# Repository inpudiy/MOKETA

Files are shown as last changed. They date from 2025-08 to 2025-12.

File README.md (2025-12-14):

# MOKETA

MOKETA is an open-source unibody 42-key wireless keyboard with MX switches, per-key LEDs, status indicators, a 3D-printed box-mount case, and a hot-swappable Pro Micro–compatible controller.

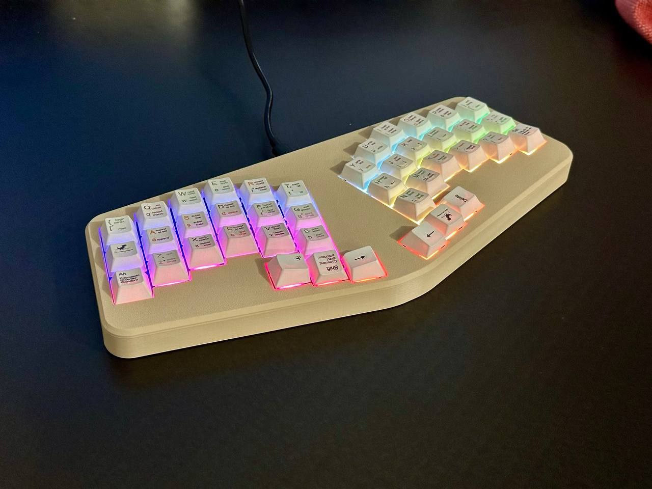
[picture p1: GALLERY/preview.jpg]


[Build Guide](BUILD.md) | [ZMK Firmware](https://github.com/inpudiy/zmk-MOKETA)

## Features

- Unibody form factor with a 15 degree angle between halves
- 42-key column-staggered layout with MX switches
- 3D-printed box mount case
- 4 status LEDs inspired by the Aroum project
- Per-switch SK6812MINI-E LEDs
- Pro Micro compatible microcontroller with hot-swap (nice!nano, SuperMini NRF52840, Mikoto, or another)
- Optimized for wireless use: hardware power switch, reset button, battery solder pads, and ZMK firmware

## PCB Image




## Bill of materials

| Component | Qty/Pin |
| --- | --- |
| Pro Micro board: Super Mini nRF52840 / nice!nano | 1 |
| MSK12C02 Slide Switch | 1 |
| TS342A2P | 1 |
| 50mm Industrial H62 brass wire 0.5mm thickness | 1 |
| 0805 Led | 4 |
| 0805 Resitor | 4 |
| Silicone bumpers | 6 |
| Machine Pin Header Female | 24 |
| PG1511 hot-swap socket | 42 |
| Diode 1N4148W (SOD-123) | 42 |
| MX switches | 42 |
| SK6812MINI-E | 42 |
| Silicone (Optional)

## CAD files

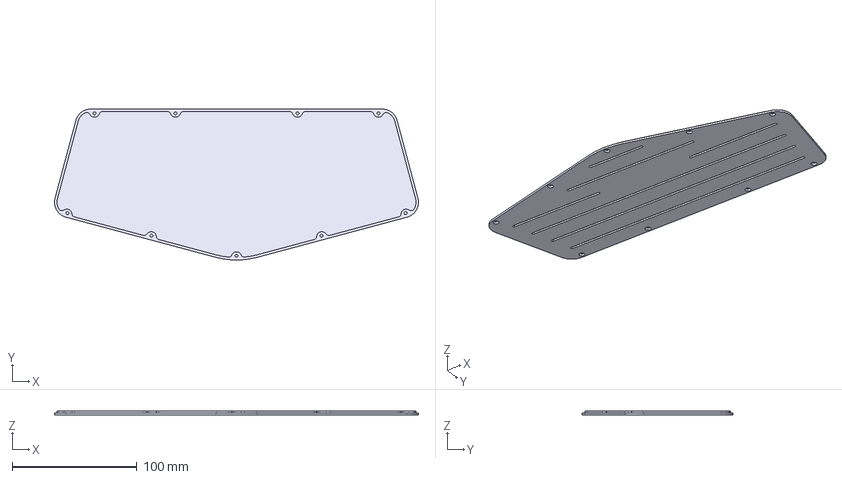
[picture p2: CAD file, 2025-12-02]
CASE/turtle/MOKETA-bottom.step
291.8 x 121.0 x 3.00 mm

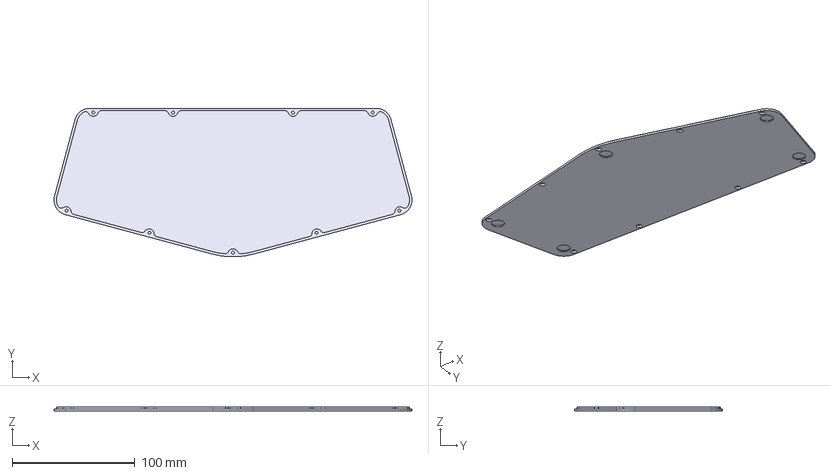
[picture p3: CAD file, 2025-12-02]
CASE/turtle/MOKETA-bottom-for-siliconepads-10mm.step
291.8 x 121.0 x 3.00 mm

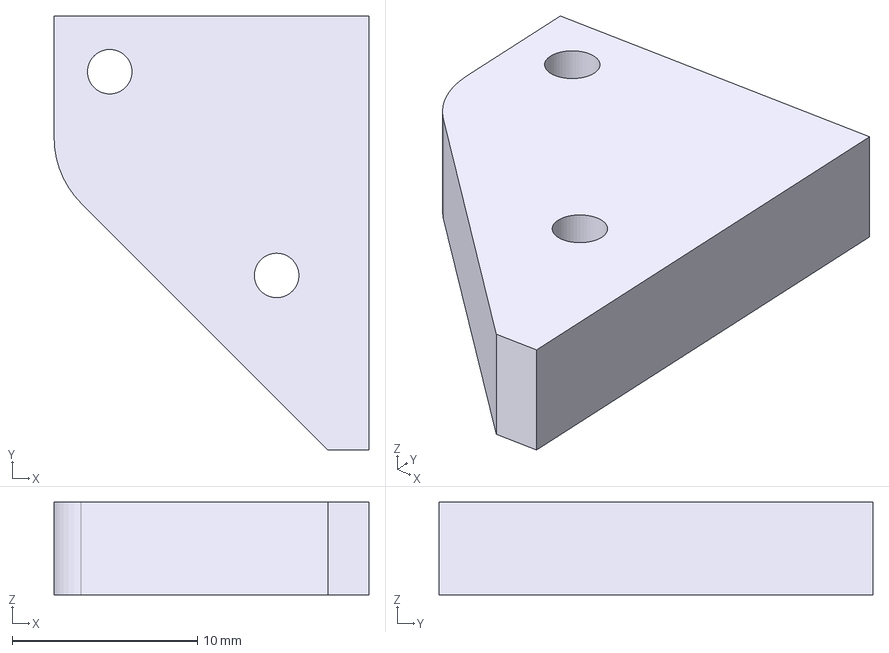
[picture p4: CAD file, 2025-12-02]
CASE/turtle/MOKETA-top-filler-mcu-around-left.step
17.0 x 23.4 x 5.00 mm

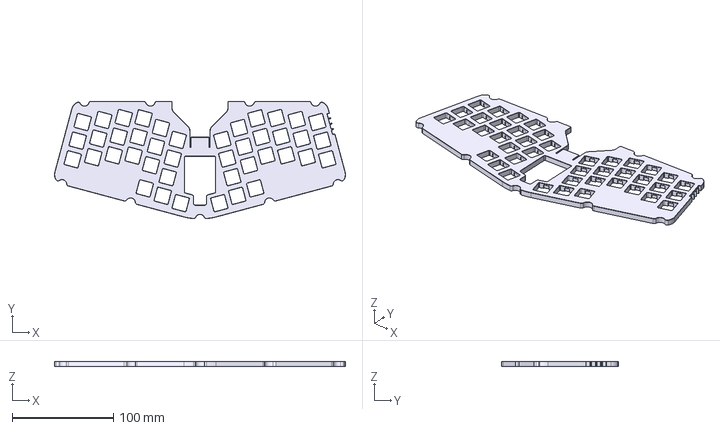
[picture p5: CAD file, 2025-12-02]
CASE/turtle/MOKETA-switchplate.step
286.8 x 115.6 x 5.00 mm

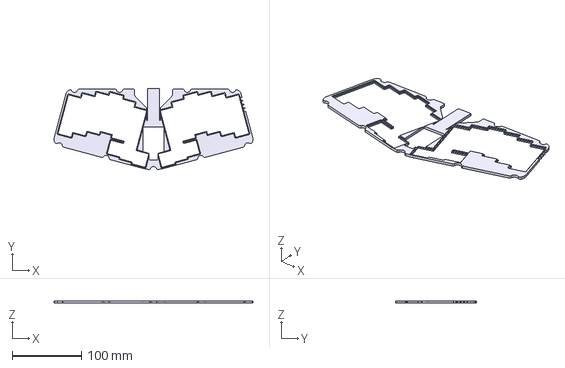
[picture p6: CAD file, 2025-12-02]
CASE/turtle/MOKETA-top-filler.step
286.8 x 116.4 x 3.00 mm

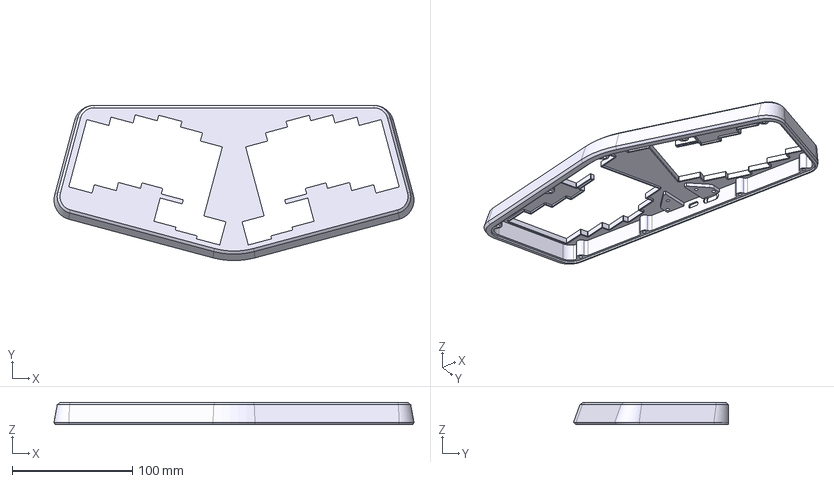
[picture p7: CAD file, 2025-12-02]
CASE/turtle/MOKETA-top.step
300.0 x 129.2 x 18.6 mm

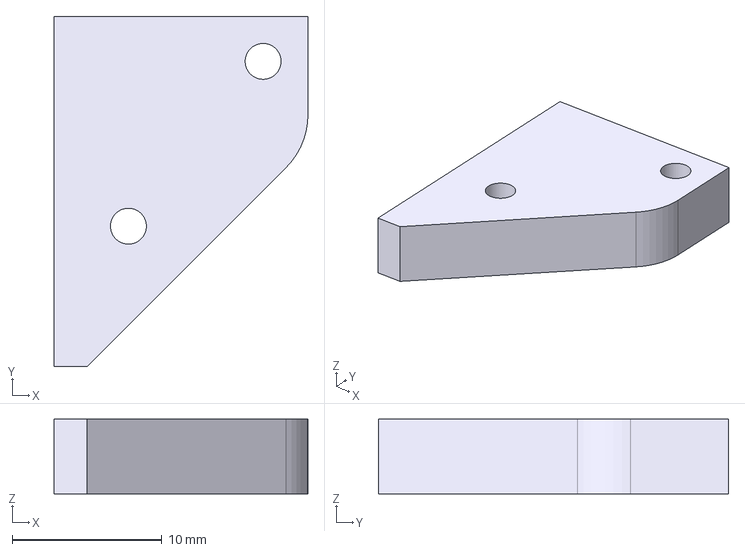
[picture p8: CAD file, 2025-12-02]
CASE/turtle/MOKETA-top-filler-mcu-around-right.step
17.0 x 23.4 x 5.00 mm

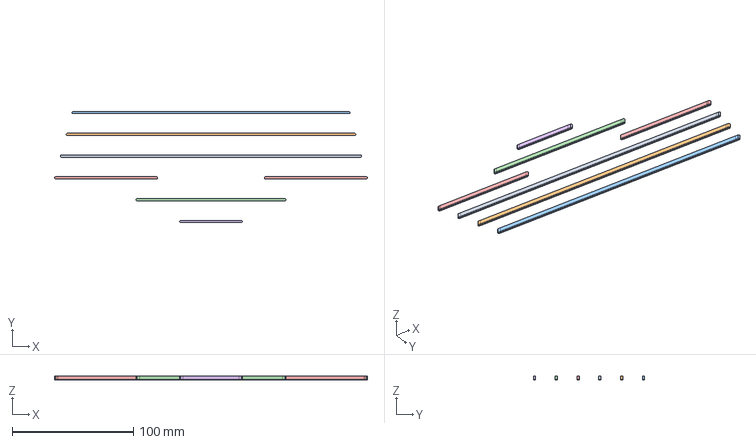
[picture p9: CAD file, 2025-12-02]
CASE/turtle/MOKETA-anti-slippery-legs.step
258.5 x 92.0 x 3.40 mm

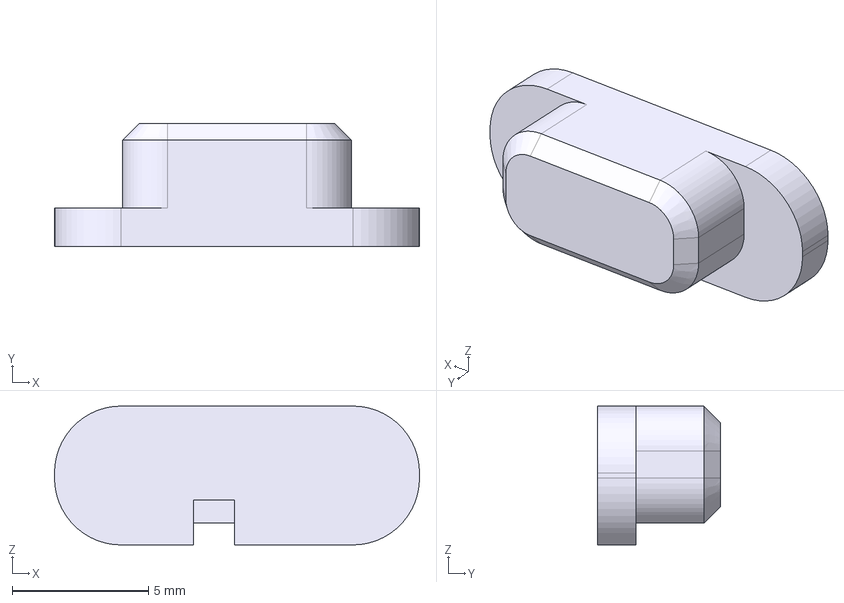
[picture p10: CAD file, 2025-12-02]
CASE/turtle/MOKETA-powerswitch-pusher.step
13.4 x 4.50 x 5.10 mm

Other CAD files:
CASE/turtle/MOKETA-bottom-for-siliconepads-8mm.step
CASE/turtle/MOKETA-top-with-moketa.step
CASE/turtle/MOKETA-bottom-filler.step

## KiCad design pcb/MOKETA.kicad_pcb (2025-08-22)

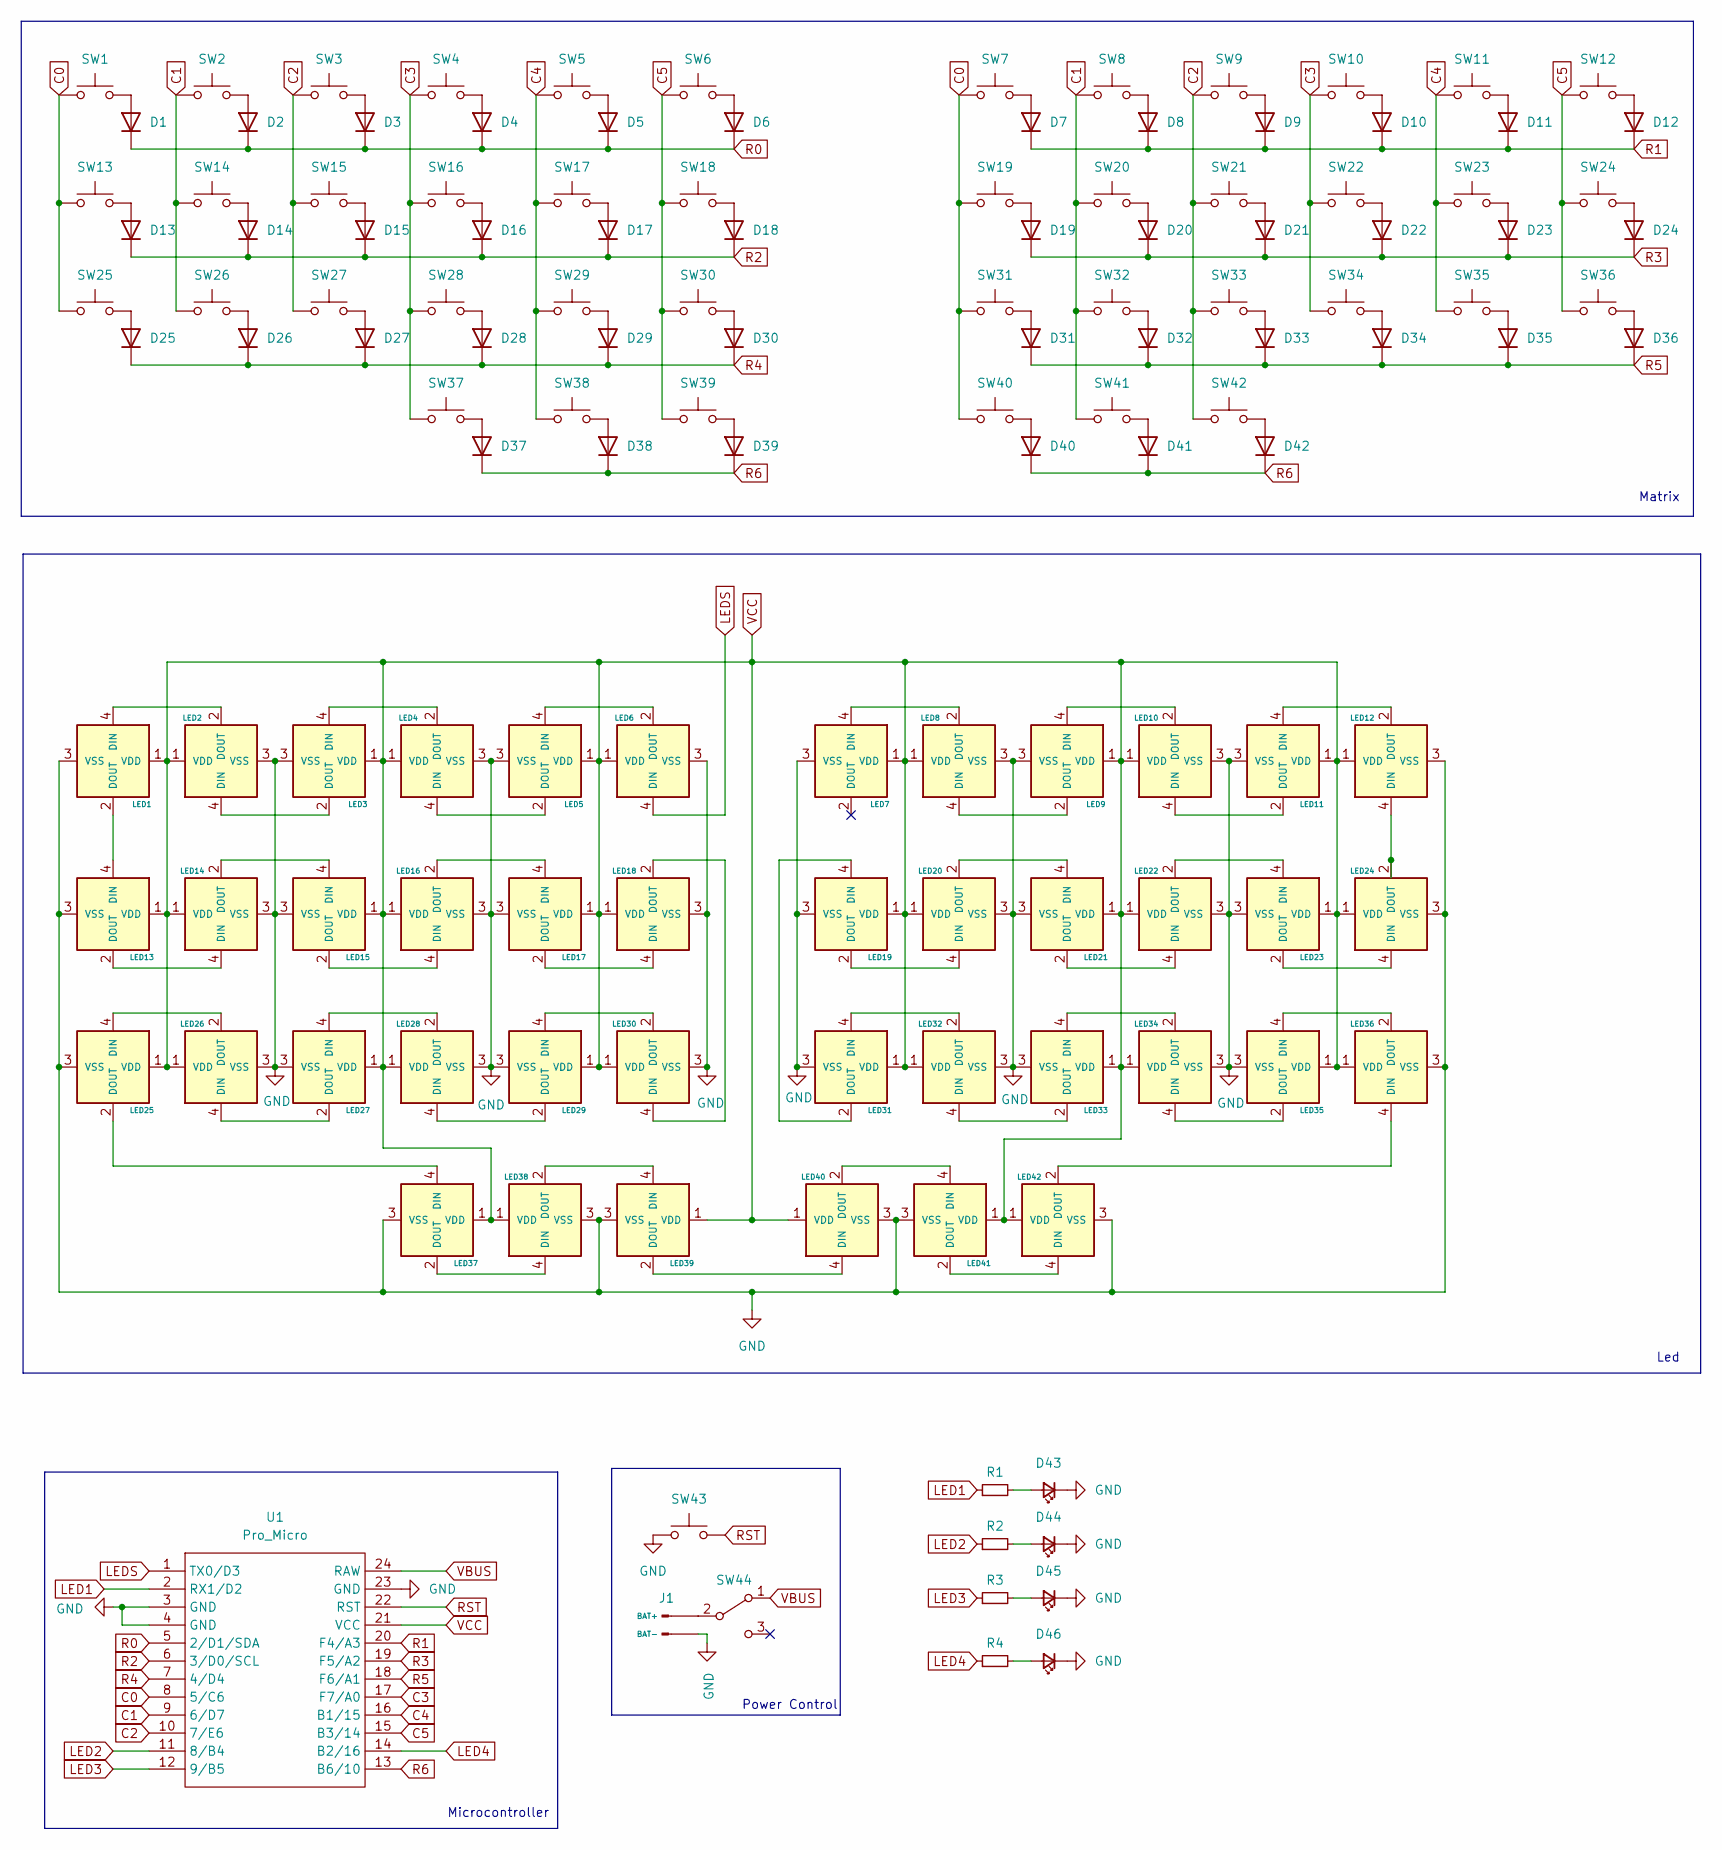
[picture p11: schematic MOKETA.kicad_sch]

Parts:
D1, D2, D3, D4, D5, D6, D7, D8, D9, D10, D11, D12, D13, D14, D15, D16, D17, D18, D19, D20, D21, D22, D23, D24, D25, D26, D27, D28, D29, D30, D31, D32, D33, D34, D35, D36, D37, D38, D39, D40, D41, D42: Diode; D_SOD-123
D43, D44, D45, D46: LED_1206
J1: J_BATTERY
LED1, LED2, LED3, LED4, LED5, LED6, LED7, LED8, LED9, LED10, LED11, LED12, LED13, LED14, LED15, LED16, LED17, LED18, LED19, LED20, LED21, LED22, LED23, LED24, LED25, LED26, LED27, LED28, LED29, LED30, LED31, LED32, LED33, LED34, LED35, LED36, LED37, LED38, LED39, LED40, LED41, LED42: YS-SK6812MINI-E
R1, R2, R3, R4: R_1206_3216
SW1, SW2, SW3, SW4, SW5, SW6, SW7, SW8, SW9, SW10, SW11, SW12, SW13, SW14, SW15, SW16, SW17, SW18, SW19, SW20, SW21, SW22, SW23, SW24, SW25, SW26, SW27, SW28, SW29, SW30, SW31, SW32, SW33, SW34, SW35, SW36, SW37, SW38, SW39, SW40, SW41, SW42: SW_PUSH
SW43: Reset; SW_TACT
SW44: MSK-12C02
U1: Pro_Micro; U_PRO_MICRO

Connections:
C0: SW1.1, SW7.1, SW13.1, SW19.1, SW25.1, SW31.1, SW40.1, U1.8 (5/C6)
C1: SW2.1, SW8.1, SW14.1, SW20.1, SW26.1, SW32.1, SW41.1, U1.9 (6/D7)
C2: SW3.1, SW9.1, SW15.1, SW21.1, SW27.1, SW33.1, SW42.1, U1.10 (7/E6)
C3: SW4.1, SW10.1, SW16.1, SW22.1, SW28.1, SW34.1, SW37.1, U1.17 (F7/A0)
C4: SW5.1, SW11.1, SW17.1, SW23.1, SW29.1, SW35.1, SW38.1, U1.16 (B1/15)
C5: SW6.1, SW12.1, SW18.1, SW24.1, SW30.1, SW36.1, SW39.1, U1.15 (B3/14)
GND: D43.1 (K), D44.1 (K), D45.1 (K), D46.1 (K), J1.2 (BAT-), LED1.3 (VSS), LED2.3 (VSS), LED3.3 (VSS), LED4.3 (VSS), LED5.3 (VSS), LED6.3 (VSS), LED7.3 (VSS), LED8.3 (VSS), LED9.3 (VSS), LED10.3 (VSS), LED11.3 (VSS), LED12.3 (VSS), LED13.3 (VSS), LED14.3 (VSS), LED15.3 (VSS), LED16.3 (VSS), LED17.3 (VSS), LED18.3 (VSS), LED19.3 (VSS), LED20.3 (VSS), LED21.3 (VSS), LED22.3 (VSS), LED23.3 (VSS), LED24.3 (VSS), LED25.3 (VSS), LED26.3 (VSS), LED27.3 (VSS), LED28.3 (VSS), LED29.3 (VSS), LED30.3 (VSS), LED31.3 (VSS), LED32.3 (VSS), LED33.3 (VSS), LED34.3 (VSS), LED35.3 (VSS), LED36.3 (VSS), LED37.3 (VSS), LED38.3 (VSS), LED39.3 (VSS), LED40.3 (VSS), LED41.3 (VSS), LED42.3 (VSS), SW43.1, U1.3 (GND), U1.4 (GND), U1.23 (GND)
LED1: R1.1, U1.2 (RX1/D2)
LED2: R2.1, U1.11 (8/B4)
LED3: R3.1, U1.12 (9/B5)
LED4: R4.1, U1.14 (B2/16)
LEDS: LED6.4 (DIN), U1.1 (TX0/D3)
unnamed: D1.2 (A), SW1.2
unnamed: D2.2 (A), SW2.2
unnamed: D3.2 (A), SW3.2
unnamed: D4.2 (A), SW4.2
unnamed: D5.2 (A), SW5.2
unnamed: D6.2 (A), SW6.2
unnamed: D7.2 (A), SW7.2
unnamed: D8.2 (A), SW8.2
unnamed: D9.2 (A), SW9.2
unnamed: D10.2 (A), SW10.2
unnamed: D11.2 (A), SW11.2
unnamed: D12.2 (A), SW12.2
unnamed: D13.2 (A), SW13.2
unnamed: D14.2 (A), SW14.2
unnamed: D15.2 (A), SW15.2
unnamed: D16.2 (A), SW16.2
unnamed: D17.2 (A), SW17.2
unnamed: D18.2 (A), SW18.2
unnamed: D19.2 (A), SW19.2
unnamed: D20.2 (A), SW20.2
unnamed: D21.2 (A), SW21.2
unnamed: D22.2 (A), SW22.2
unnamed: D23.2 (A), SW23.2
unnamed: D24.2 (A), SW24.2
unnamed: D25.2 (A), SW25.2
unnamed: D26.2 (A), SW26.2
unnamed: D27.2 (A), SW27.2
unnamed: D28.2 (A), SW28.2
unnamed: D29.2 (A), SW29.2
unnamed: D30.2 (A), SW30.2
unnamed: D31.2 (A), SW31.2
unnamed: D32.2 (A), SW32.2
unnamed: D33.2 (A), SW33.2
unnamed: D34.2 (A), SW34.2
unnamed: D35.2 (A), SW35.2
unnamed: D36.2 (A), SW36.2
unnamed: D37.2 (A), SW37.2
unnamed: D38.2 (A), SW38.2
unnamed: D39.2 (A), SW39.2
unnamed: D40.2 (A), SW40.2
unnamed: D41.2 (A), SW41.2
unnamed: D42.2 (A), SW42.2
unnamed: D43.2 (A), R1.2
unnamed: D44.2 (A), R2.2
unnamed: D45.2 (A), R3.2
unnamed: D46.2 (A), R4.2
unnamed: J1.1 (BAT+), SW44.2 (B)
unnamed: LED1.4 (DIN), LED2.2 (DOUT)
unnamed: LED1.2 (DOUT), LED13.4 (DIN)
unnamed: LED2.4 (DIN), LED3.2 (DOUT)
unnamed: LED3.4 (DIN), LED4.2 (DOUT)
unnamed: LED4.4 (DIN), LED5.2 (DOUT)
unnamed: LED5.4 (DIN), LED6.2 (DOUT)
unnamed: LED7.4 (DIN), LED8.2 (DOUT)
unnamed: LED8.4 (DIN), LED9.2 (DOUT)
unnamed: LED10.4 (DIN), LED11.2 (DOUT)
unnamed: LED9.4 (DIN), LED10.2 (DOUT)
unnamed: LED11.4 (DIN), LED12.2 (DOUT)
unnamed: LED12.4 (DIN), LED24.2 (DOUT)
unnamed: LED13.2 (DOUT), LED14.4 (DIN)
unnamed: LED14.2 (DOUT), LED15.4 (DIN)
unnamed: LED15.2 (DOUT), LED16.4 (DIN)
unnamed: LED16.2 (DOUT), LED17.4 (DIN)
unnamed: LED17.2 (DOUT), LED18.4 (DIN)
unnamed: LED18.2 (DOUT), LED30.4 (DIN)
unnamed: LED19.4 (DIN), LED31.2 (DOUT)
unnamed: LED19.2 (DOUT), LED20.4 (DIN)
unnamed: LED20.2 (DOUT), LED21.4 (DIN)
unnamed: LED21.2 (DOUT), LED22.4 (DIN)
unnamed: LED22.2 (DOUT), LED23.4 (DIN)
unnamed: LED23.2 (DOUT), LED24.4 (DIN)
unnamed: LED25.4 (DIN), LED26.2 (DOUT)
unnamed: LED25.2 (DOUT), LED37.4 (DIN)
unnamed: LED26.4 (DIN), LED27.2 (DOUT)
unnamed: LED27.4 (DIN), LED28.2 (DOUT)
unnamed: LED28.4 (DIN), LED29.2 (DOUT)
unnamed: LED29.4 (DIN), LED30.2 (DOUT)
unnamed: LED31.4 (DIN), LED32.2 (DOUT)
unnamed: LED32.4 (DIN), LED33.2 (DOUT)
unnamed: LED33.4 (DIN), LED34.2 (DOUT)
unnamed: LED34.4 (DIN), LED35.2 (DOUT)
unnamed: LED35.4 (DIN), LED36.2 (DOUT)
unnamed: LED36.4 (DIN), LED42.2 (DOUT)
unnamed: LED37.2 (DOUT), LED38.4 (DIN)
unnamed: LED38.2 (DOUT), LED39.4 (DIN)
unnamed: LED39.2 (DOUT), LED40.4 (DIN)
unnamed: LED40.2 (DOUT), LED41.4 (DIN)
unnamed: LED41.2 (DOUT), LED42.4 (DIN)
R0: D1.1 (K), D2.1 (K), D3.1 (K), D4.1 (K), D5.1 (K), D6.1 (K), U1.5 (2/D1/SDA)
R1: D7.1 (K), D8.1 (K), D9.1 (K), D10.1 (K), D11.1 (K), D12.1 (K), U1.20 (F4/A3)
R2: D13.1 (K), D14.1 (K), D15.1 (K), D16.1 (K), D17.1 (K), D18.1 (K), U1.6 (3/D0/SCL)
R3: D19.1 (K), D20.1 (K), D21.1 (K), D22.1 (K), D23.1 (K), D24.1 (K), U1.19 (F5/A2)
R4: D25.1 (K), D26.1 (K), D27.1 (K), D28.1 (K), D29.1 (K), D30.1 (K), U1.7 (4/D4)
R5: D31.1 (K), D32.1 (K), D33.1 (K), D34.1 (K), D35.1 (K), D36.1 (K), U1.18 (F6/A1)
R6: D37.1 (K), D38.1 (K), D39.1 (K), D40.1 (K), D41.1 (K), D42.1 (K), U1.13 (B6/10)
RST: SW43.2, U1.22 (RST)
VBUS: SW44.1 (A), U1.24 (RAW)
VCC: LED1.1 (VDD), LED2.1 (VDD), LED3.1 (VDD), LED4.1 (VDD), LED5.1 (VDD), LED6.1 (VDD), LED7.1 (VDD), LED8.1 (VDD), LED9.1 (VDD), LED10.1 (VDD), LED11.1 (VDD), LED12.1 (VDD), LED13.1 (VDD), LED14.1 (VDD), LED15.1 (VDD), LED16.1 (VDD), LED17.1 (VDD), LED18.1 (VDD), LED19.1 (VDD), LED20.1 (VDD), LED21.1 (VDD), LED22.1 (VDD), LED23.1 (VDD), LED24.1 (VDD), LED25.1 (VDD), LED26.1 (VDD), LED27.1 (VDD), LED28.1 (VDD), LED29.1 (VDD), LED30.1 (VDD), LED31.1 (VDD), LED32.1 (VDD), LED33.1 (VDD), LED34.1 (VDD), LED35.1 (VDD), LED36.1 (VDD), LED37.1 (VDD), LED38.1 (VDD), LED39.1 (VDD), LED40.1 (VDD), LED41.1 (VDD), LED42.1 (VDD), U1.21 (VCC)

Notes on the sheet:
Matrix
Power Control
Microcontroller
Led

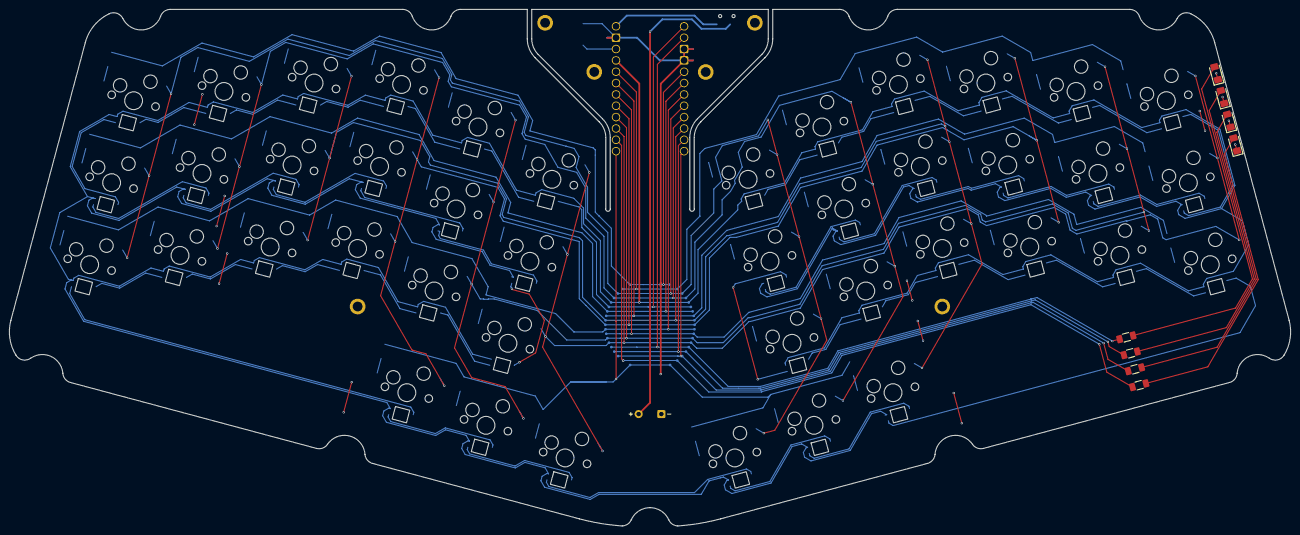
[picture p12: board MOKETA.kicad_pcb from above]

Board: 2 copper layers, 286.8 x 115.6 mm, 144 parts (0 on the bottom side), 110 nets.

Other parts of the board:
MH: Untitled; M2 Hole
MH#2, MH#3, MH#4, MH#5, MH#6: Untitled; M2 Hole

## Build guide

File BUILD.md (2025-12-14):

## 1. Soldering the diodes,hotswap and LED

Install the hotswap and solder it. Install the diode with the stripe facing up, and the LED with the trimmed leg toward the corner. All LEDs and diodes should face the same direction.

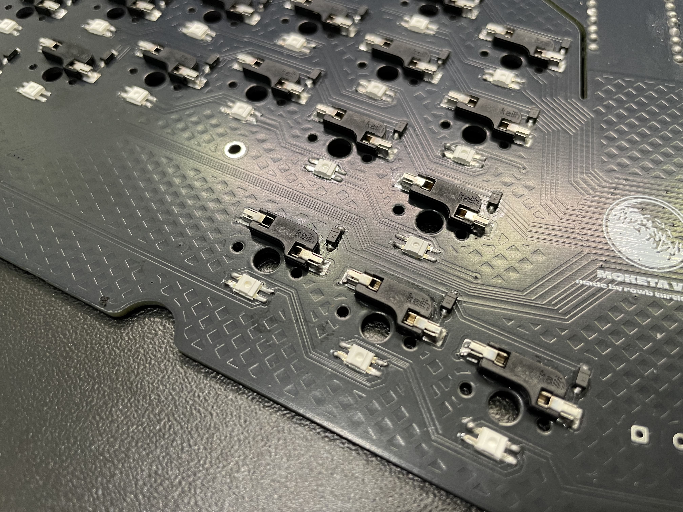
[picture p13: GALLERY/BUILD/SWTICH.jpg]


## 2. Solder MCU

Install the controller sockets on the top side of the board; trim the pins on the bottom side and solder them. Solder the sockets or wires for the controller, then insert the controller into the socket.

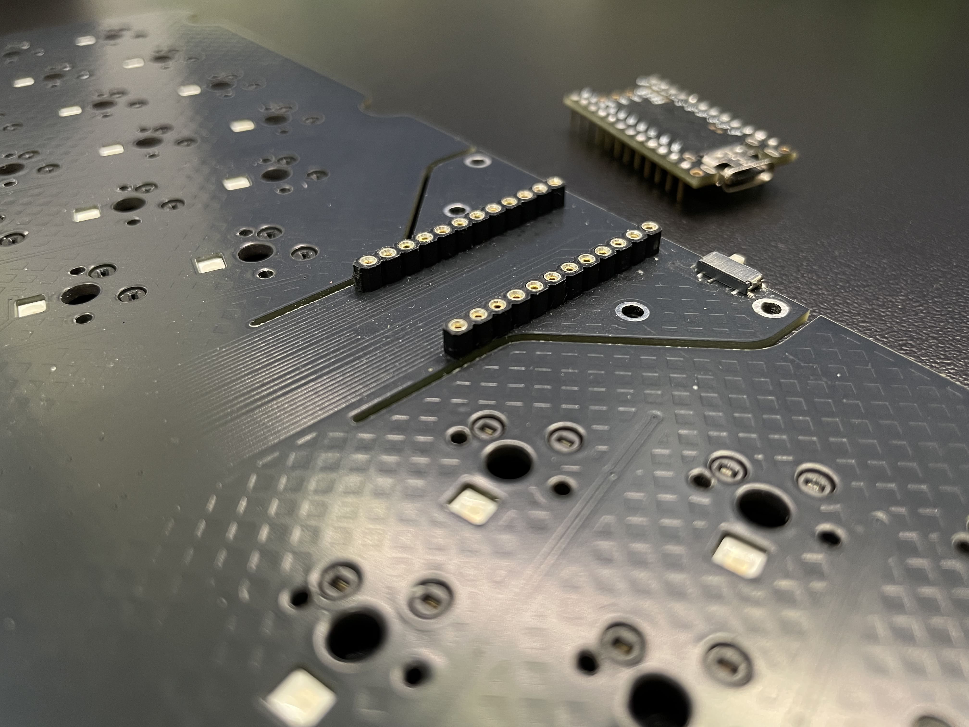
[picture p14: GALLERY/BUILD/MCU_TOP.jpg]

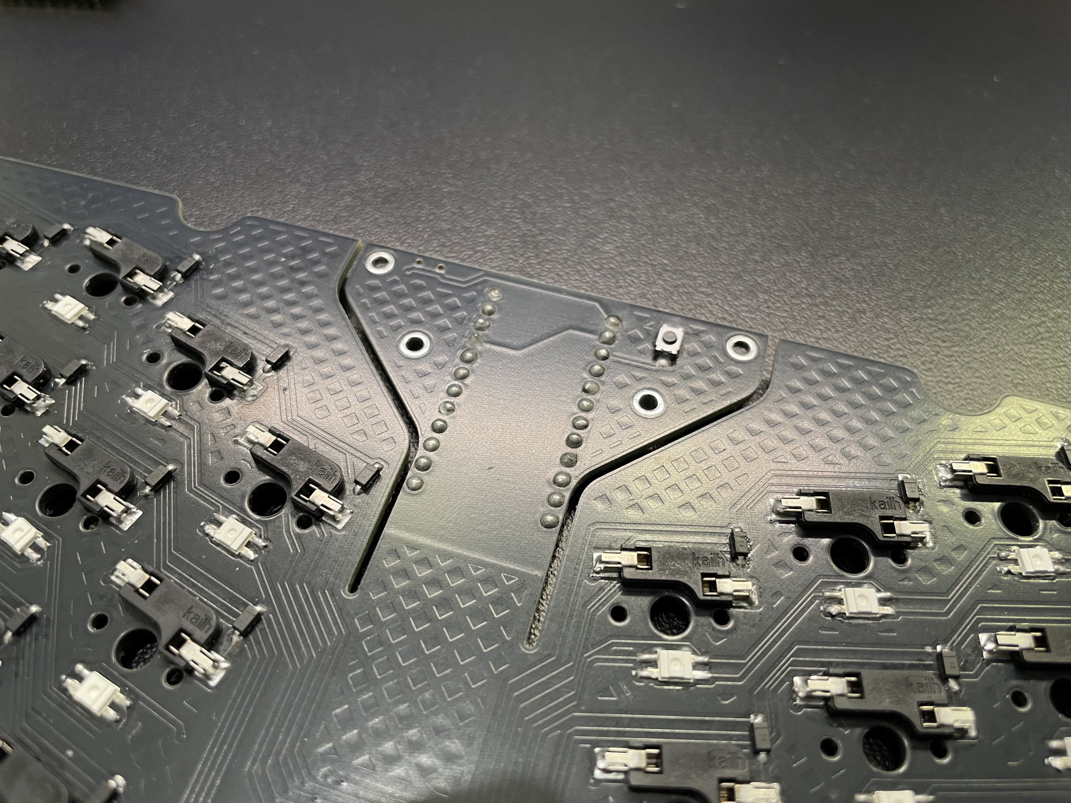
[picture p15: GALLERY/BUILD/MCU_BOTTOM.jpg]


## 3. Solder control switch

Solder MSK12C02 on the top, and TS342A2P on the bottom side PCB

## 4. Solder resistor and LED

Install the 0805 LED with the green side facing down, and install the resistor (the resistor’s polarity does not matter).

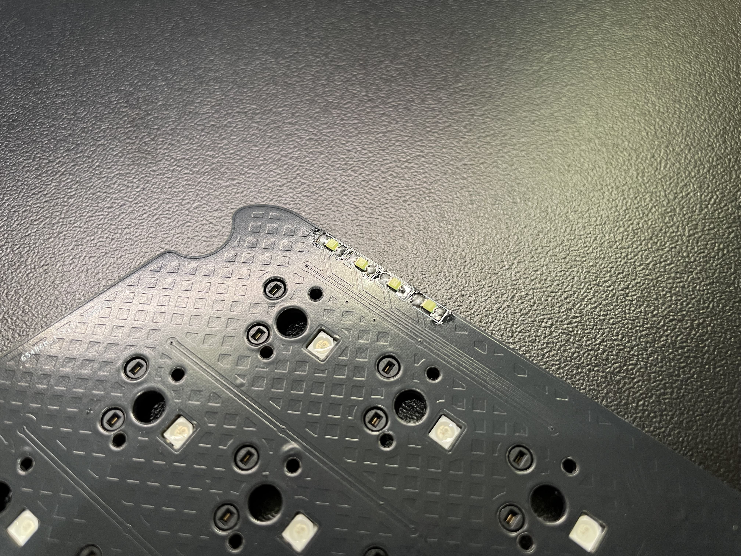
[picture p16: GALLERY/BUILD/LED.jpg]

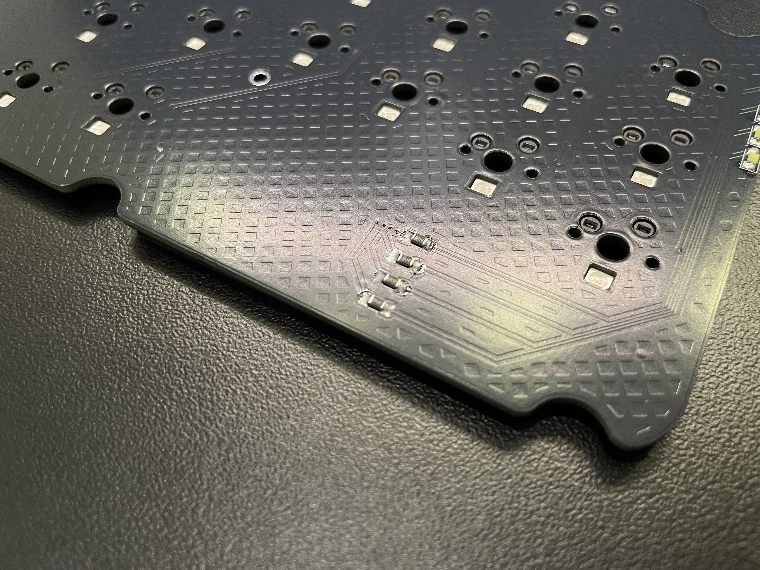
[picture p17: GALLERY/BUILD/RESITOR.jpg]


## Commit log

2025-07-18 add switches
    [MOKETA.kicad_pcb, MOKETA.kicad_sch, MOKETA.step]
2025-07-20 New MOKETA otuline
    [MOKETA.kicad_pcb]
2025-07-28 aling col and row
    [MOKETA.kicad_pcb, MOKETA.kicad_sch]
2025-07-28 add footrpint
    [MOKETA.kicad_pcb, MOKETA.kicad_sch]
2025-07-28 fix LED footprint
    [MOKETA.kicad_pcb]
2025-07-29 update footprint
    [MOKETA.kicad_pcb, MOKETA.kicad_sch]
2025-07-30 add RGB to scheme
    [MOKETA.kicad_sch]
2025-07-30 some fix
    [MOKETA.kicad_pcb, MOKETA.kicad_sch]
2025-07-30 fix led
    [MOKETA.kicad_sch]
2025-07-30 update LED footprint
2025-07-30 add outline
    [MOKETA.kicad_pcb, MOKETA.kicad_sch]
2025-08-02 Basic routing
    [MOKETA.kicad_pcb, MOKETA.kicad_sch]
2025-08-06 change footrpint
    [MOKETA.kicad_pcb, MOKETA.kicad_sch]
2025-08-12 Doter pcb base cut
    [MOKETA.kicad_pcb]
2025-08-12 update footptint
    [MOKETA.kicad_pcb]
2025-08-13 Basic routing on almost whole board
    [MOKETA.kicad_pcb, MOKETA.kicad_sch]
2025-08-18 update footpint
    [MOKETA.kicad_pcb]
2025-08-18 Extended board, 38 mm between thumbs
    [MOKETA.kicad_sch]
2025-08-19 Connector on doter rotated 180 degree
    [MOKETA.kicad_pcb, MOKETA.kicad_sch]
2025-08-21 add hole
2025-08-22 No separate doter, flex PCB instead
    [MOKETA.kicad_pcb, MOKETA.kicad_sch]
2025-08-22 Add another 2 holes on controller zone
    [MOKETA.kicad_pcb]
2025-08-22 pre release upload
    [MOKETA-B_Cu.gbr, MOKETA-B_Mask.gbr, MOKETA-B_Paste.gbr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]
2025-08-24 Hole pads placement fix
2025-08-24 last fix
    [MOKETA-B_Cu.gbr, MOKETA-B_Mask.gbr, MOKETA-B_Paste.gbr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]
2025-08-24 fix silc
    [MOKETA-B_Cu.gbr, MOKETA-B_Mask.gbr, MOKETA-B_Paste.gbr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]
2025-08-24 fix brandmark
    [MOKETA-B_Cu.gbr, MOKETA-B_Mask.gbr, MOKETA-B_Paste.gbr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]
2025-08-25 Fix power lines from power switch
    [MOKETA.step]
2025-08-25 Move micro via near power switch
2025-08-26 generate gerber
    [MOKETA-B_Cu.gbr, MOKETA-B_Mask.gbr, MOKETA-B_Paste.gbr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]
2025-11-02 add README.md
    [MOKETA.kicad_sch]
2025-12-02 Case TE files added
    [MOKETA-anti-slippery-legs.step, MOKETA-bottom-filler.step, MOKETA-bottom.step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]
2025-12-02 Added bottom variations for silicone pads 8mm and 10mm
    [MOKETA-bottom-for-siliconepads-10mm.step, MOKETA-bottom-for-siliconepads-8mm.step, MOKETA-bottom.step]
2025-12-14 add BUILD GUIDE
    [MOKETA-anti-slippery-legs.step, MOKETA-bottom-filler.step, MOKETA-bottom-for-siliconepads-10mm.step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]
